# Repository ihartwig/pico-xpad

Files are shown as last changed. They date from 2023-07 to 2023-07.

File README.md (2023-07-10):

# pico-xpad
Raspberry Pi Pico Xinput focused Macropad / Gamepad

## Hardware
Folders in this repository have different hardware variations of the xpad.

### selectomatic-hw
Get you fingers ready to select as many buttons as DirectInput allows.

* 18 buttons (12 numbered keys + 4 directional keys + 2 special buttons)

### thumbs-down-hw
Pencils down folks; try out development ideas with this compact Pico + Feather Wing combo.

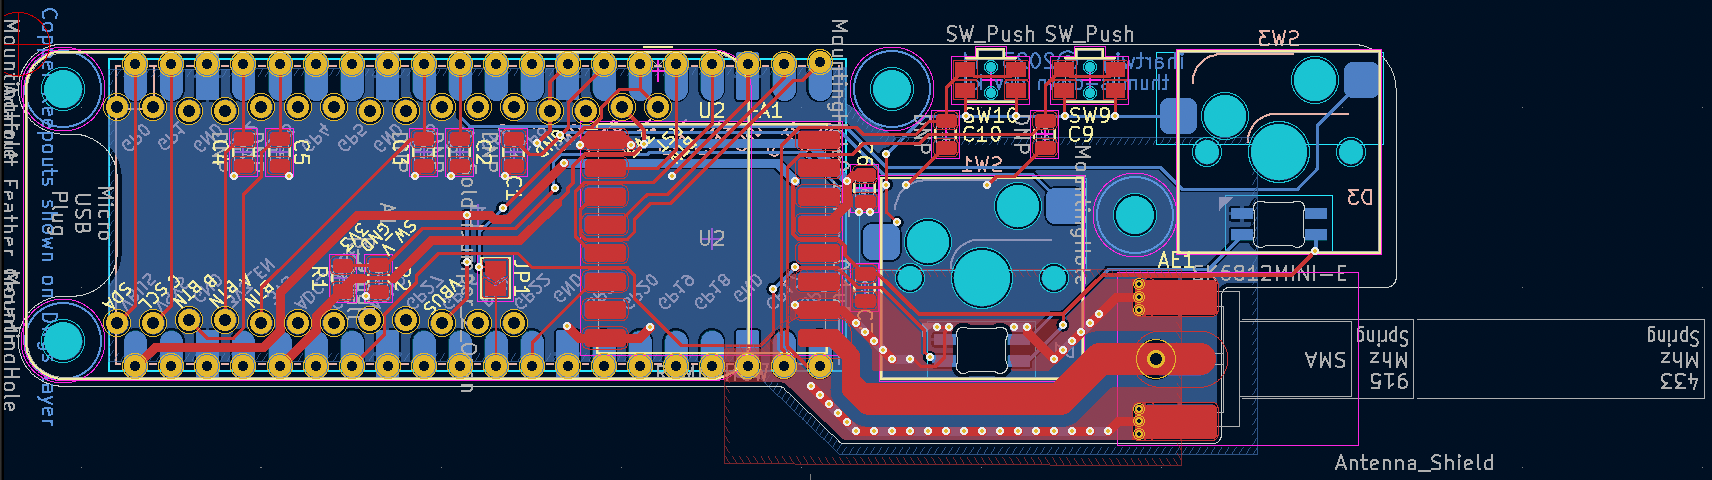
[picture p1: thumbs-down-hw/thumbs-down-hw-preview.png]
thumbs-down-hw preview


* dev kit for keys / usb / wireless with GP2040 FW or with CircuitPython 
* 4 buttons (2 keys + 2 special buttons)
* feather wing socket
** 4 more buttons w/ OLED display wing
* [RFM69HCW](https://www.adafruit.com/product/5692) module for 915/433Mhz wireless
** compact spring antenna (for [915](https://www.adafruit.com/product/4269)/[433](https://www.adafruit.com/product/4394)) or SMA connector
** footprint compatible w/ [RFM95CW](https://www.adafruit.com/product/5684) LoRA modules

## Firmware

The gamepad hardware supports running the GP2040-CE firmware out of the box.

### Compiling custom GP2040-CE firmware on MacOS

Steps to build the firmware on MacOS since this is not covered, but similar to, the steps provided in the project user guide for Linux.

```
brew update
brew install --cask gcc-arm-embedded
brew install cmake
brew install node@20
cd ~/repos
git clone https://github.com/OpenStickCommunity/GP2040-CE.git
git clone https://github.com/raspberrypi/pico-sdk.git --branch master
cd pico-sdk
git submodule update --init
cd ../
cd GP2040-CE
mkdir build
cd build
PICO_SDK_PATH=/Users/ihartwig/repos/pico-sdk cmake ..
PICO_SDK_PATH=/Users/ihartwig/repos/pico-sdk make
```

## Credits

Footprints reused from community designs:
* https://github.com/Kozova1/Macropad
* https://github.com/ebastler/kicad-keyboard-parts.pretty/
* https://datasheets.raspberrypi.com/rp2040/VGA-KiCAD.zip
* https://datasheets.raspberrypi.com/rp2040/VGA-PicoW-KiCAD.zip

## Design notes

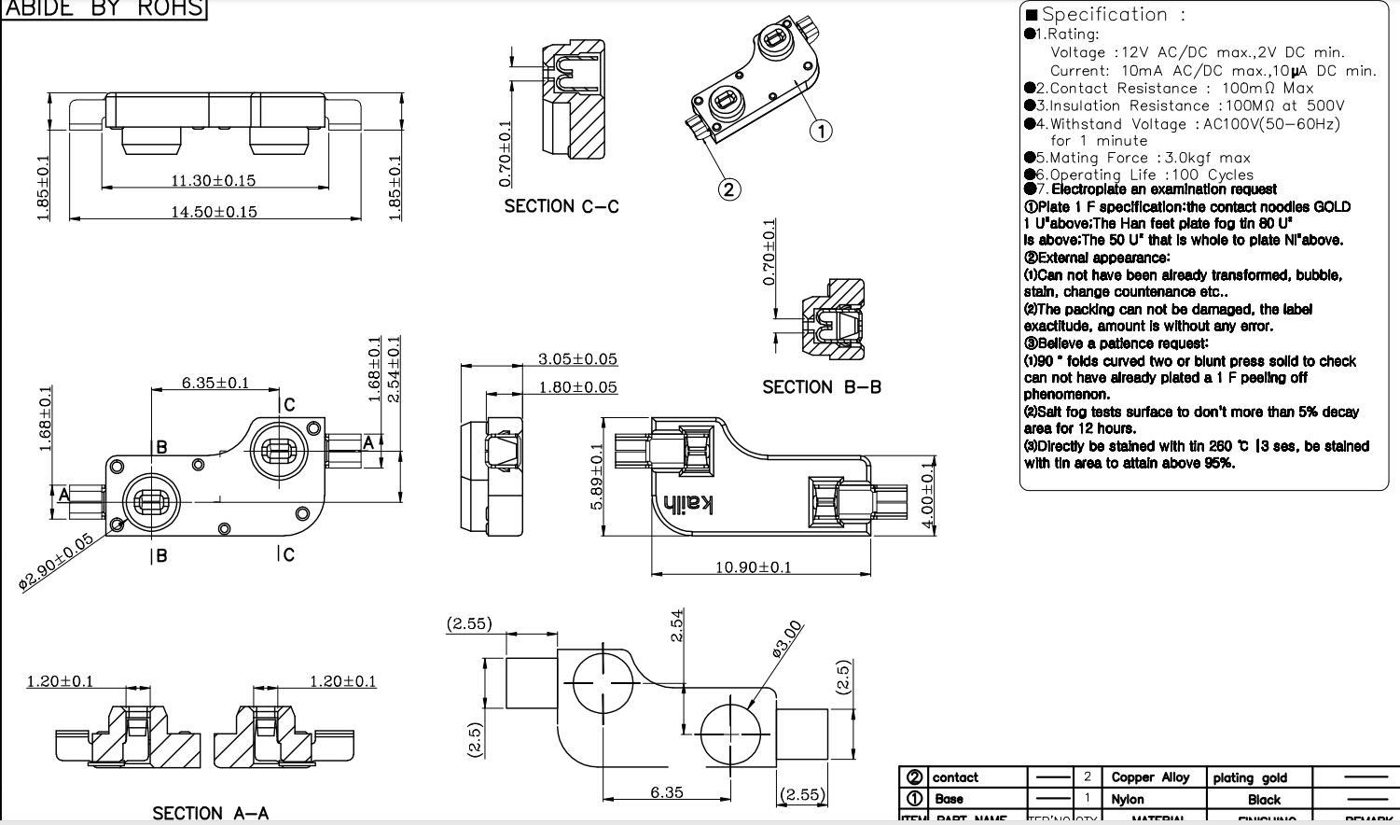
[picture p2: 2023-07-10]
docs/4958_Kailh_Key_Switch_Socket.jpeg

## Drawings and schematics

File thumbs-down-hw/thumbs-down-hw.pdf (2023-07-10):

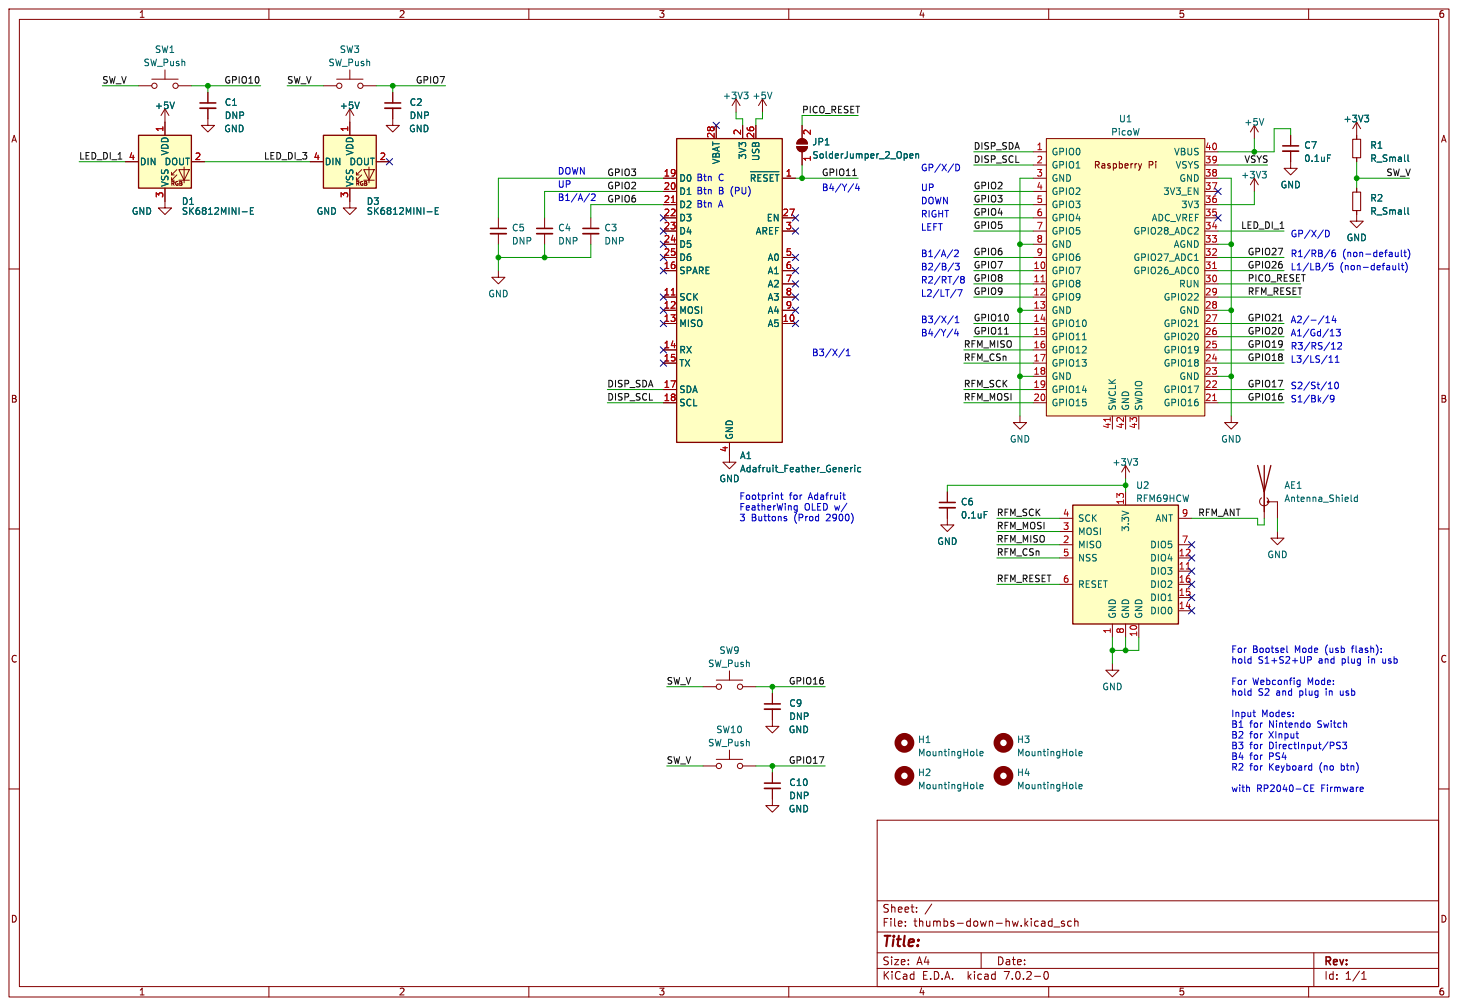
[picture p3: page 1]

2 D1 20 D2 21 D3 22 D4 23 D5 24 D6 25 USB 26 EN 27 VBAT 28 AREF 3 GND

L3/LS/11 Btn B (PU) UP

1 GND 10 DIO3 11 DIO4 12 3.3V 13 DIO0 14 DIO1 15 DIO2 16 MISO 2 MOSI 3 SCK 4 NSS 5 RESET 6 DIO5 7 GND

Id: 1/1 Title: File: thumbs-down-hw.kicad_sch Sheet: /

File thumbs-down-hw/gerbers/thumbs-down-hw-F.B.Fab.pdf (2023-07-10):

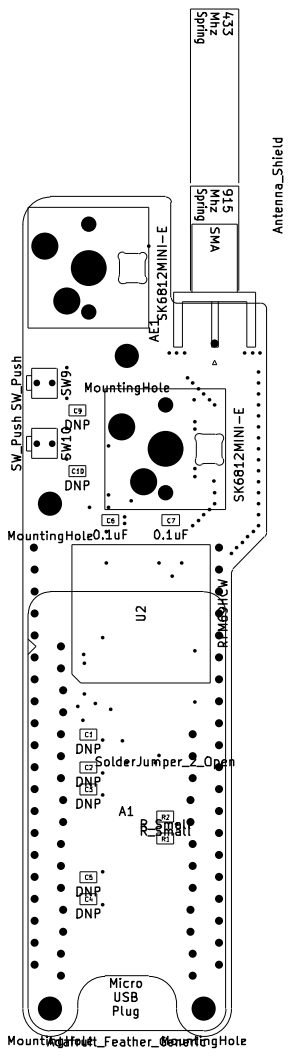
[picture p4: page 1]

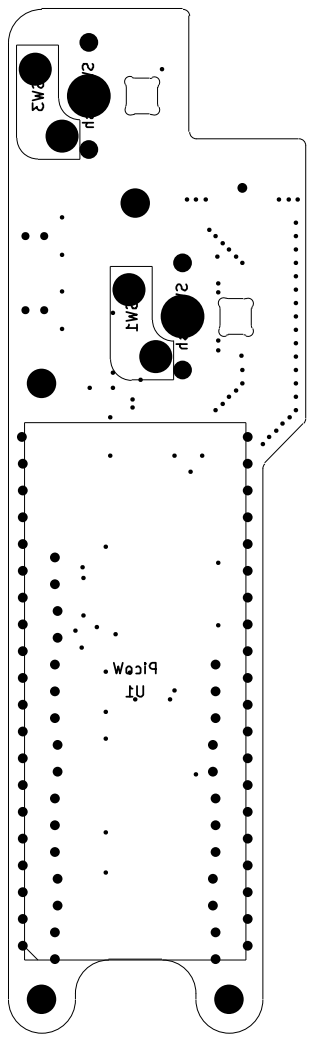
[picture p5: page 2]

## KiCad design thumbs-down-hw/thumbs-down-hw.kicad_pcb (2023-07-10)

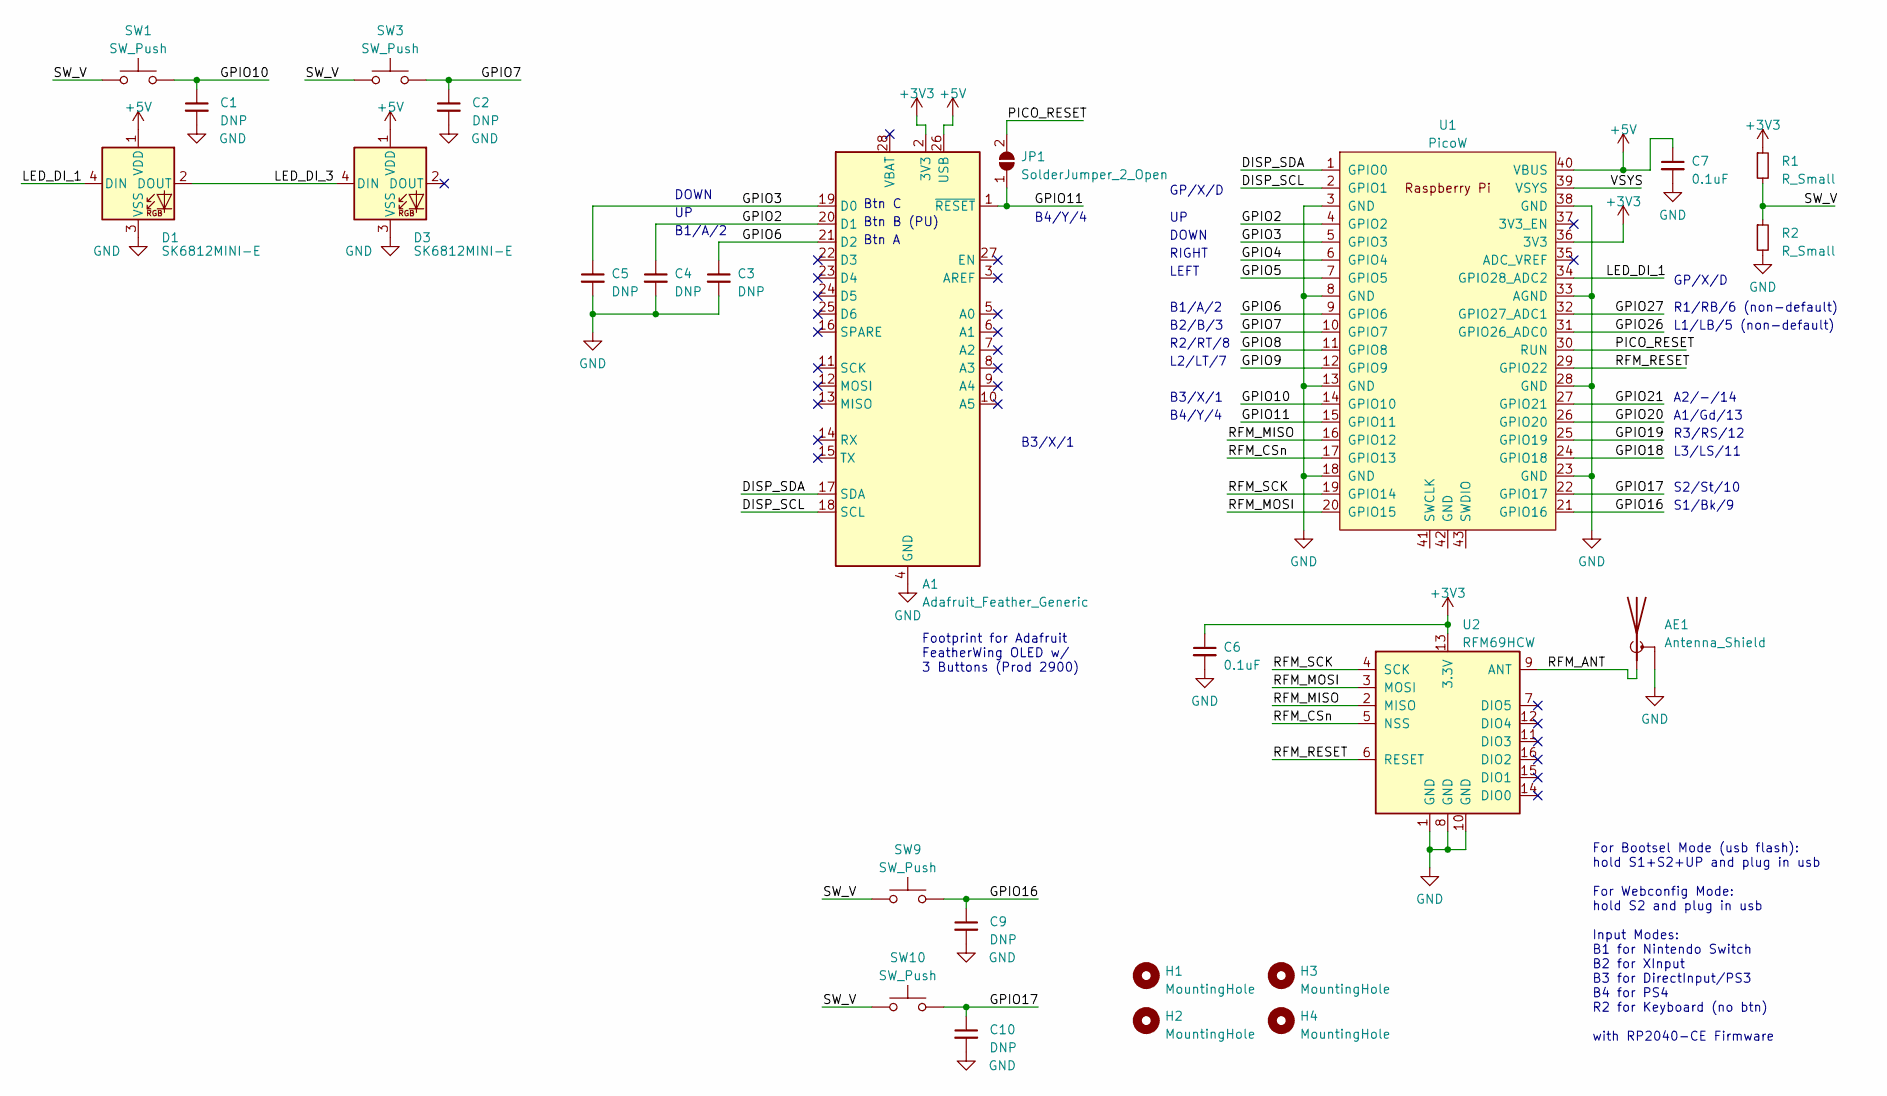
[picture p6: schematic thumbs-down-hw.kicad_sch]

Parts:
A1: Adafruit_Feather_Generic; Adafruit_Feather_Narrow
AE1: Antenna_Shield; SMA_Molex_73251-1153_EdgeMount_Horizontal_Or_Spring_Ant
C1, C2, C3, C4, C5, C9, C10: DNP; C_0805_2012Metric
C6, C7: 0.1uF; C_0805_2012Metric
D1, D3: SK6812MINI-E; LED_SK6812MINI-E_PLCC4_3.5x3.5mm_P1.75mm
H1, H2, H3, H4: MountingHole; MountingHole_2.7mm_M2.5
JP1: SolderJumper_2_Open; SolderJumper-2_P1.3mm_Open_TrianglePad1.0x1.5mm
R1: R_Small; R_0805_2012Metric
R2: R_Small; C_0805_2012Metric
SW1, SW3: SW_Push; Keyswitch_Hotswap_Kailh_1.00u
SW9, SW10: SW_Push; SW_SPST_EVQP7C
U1: PicoW; RPi_Pico_SMD_TH_Keepouts
U2: RFM69HCW; HOPERF_RFM9XW_SMD

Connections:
+3V3: A1.2 (3V3), C6.1, R1.1, U1.36 (3V3), U2.13 (3.3V)
+5V: A1.26 (USB), C7.1, D1.1 (VDD), D3.1 (VDD), U1.40 (VBUS)
/DISP_SCL: A1.18 (SCL), U1.2 (GPIO1)
/DISP_SDA: A1.17 (SDA), U1.1 (GPIO0)
/GPIO2: A1.20 (D1), C4.1, U1.4 (GPIO2)
/GPIO3: A1.19 (D0), C5.1, U1.5 (GPIO3)
/GPIO4: U1.6 (GPIO4)
/GPIO5: U1.7 (GPIO5)
/GPIO6: A1.21 (D2), C3.1, U1.9 (GPIO6)
/GPIO7: C2.1, SW3.2, U1.10 (GPIO7)
/GPIO8: U1.11 (GPIO8)
/GPIO9: U1.12 (GPIO9)
/GPIO10: C1.1, SW1.2, U1.14 (GPIO10)
/GPIO11: A1.1 (~RESET), JP1.1 (A), U1.15 (GPIO11)
/GPIO16: C9.1, SW9.2, U1.21 (GPIO16)
/GPIO17: C10.1, SW10.2, U1.22 (GPIO17)
/GPIO18: U1.24 (GPIO18)
/GPIO19: U1.25 (GPIO19)
/GPIO20: U1.26 (GPIO20)
/GPIO21: U1.27 (GPIO21)
/GPIO26: U1.31 (GPIO26_ADC0)
/GPIO27: U1.32 (GPIO27_ADC1)
/LED_DI_1: D1.4 (DIN), U1.34 (GPIO28_ADC2)
/LED_DI_3: D1.2 (DOUT), D3.4 (DIN)
/PICO_RESET: JP1.2 (B), U1.30 (RUN)
/RFM_ANT: AE1.1 (A), U2.9 (ANT)
/RFM_CSn: U1.17 (GPIO13), U2.5 (NSS)
/RFM_MISO: U1.16 (GPIO12), U2.2 (MISO)
/RFM_MOSI: U1.20 (GPIO15), U2.3 (MOSI)
/RFM_RESET: U1.29 (GPIO22), U2.6 (RESET)
/RFM_SCK: U1.19 (GPIO14), U2.4 (SCK)
/SW_V: R1.2, R2.1, SW1.1, SW3.1, SW9.1, SW10.1
/VSYS: U1.39 (VSYS)
GND: A1.4 (GND), AE1.2 (Shield), C1.2, C2.2, C3.2, C4.2, C5.2, C6.2, C7.2, C9.2, C10.2, D1.3 (VSS), D3.3 (VSS), R2.2, U1.3 (GND), U1.8 (GND), U1.13 (GND), U1.18 (GND), U1.23 (GND), U1.28 (GND), U1.33 (AGND), U1.38 (GND), U2.1 (GND), U2.8 (GND), U2.10 (GND)

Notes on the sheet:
R3/RS/12
B1/A/2
DOWN
B2/B/3
RIGHT
Btn B (PU)
GP/X/D
Btn C
A2/-/14
S2/St/10
L2/LT/7
B4/Y/4
R1/RB/6 (non-default)
B3/X/1
Footprint for Adafruit FeatherWing OLED w/ 3 Buttons (Prod 2900)
R2/RT/8
LEFT
L3/LS/11
Btn A
A1/Gd/13
For Bootsel Mode (usb flash): hold S1+S2+UP and plug in usb For Webconfig Mode: hold S2 and plug in usb Input Modes: B1 for Nintendo Switch B2 for XInput B3 for DirectInput/PS3 B4 for PS4 R2 for Keyboard (no btn) with RP2040-CE Firmware
S1/Bk/9
L1/LB/5 (non-default)

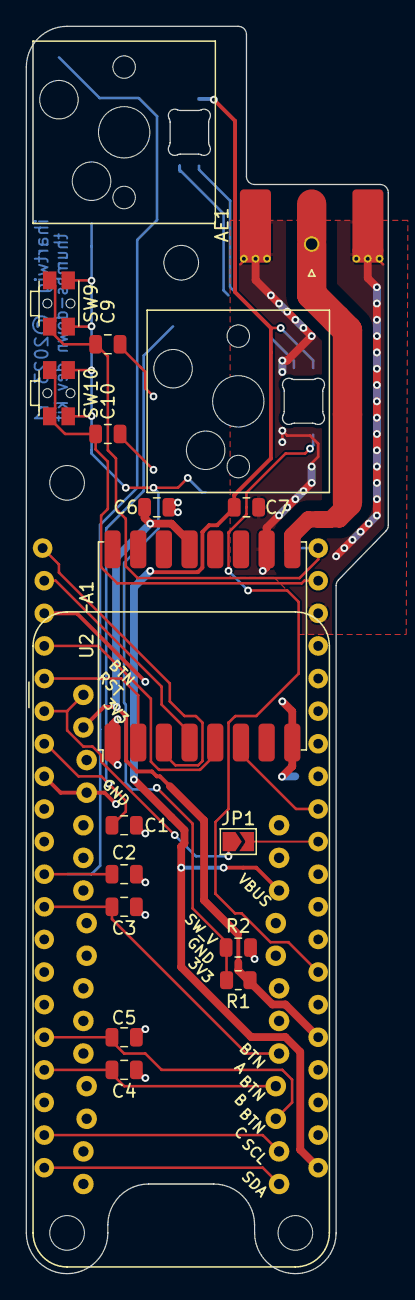
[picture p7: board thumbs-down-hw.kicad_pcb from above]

Board: 2 copper layers, 28.2 x 97.2 mm, 26 parts (1 on the bottom side), 23 nets.

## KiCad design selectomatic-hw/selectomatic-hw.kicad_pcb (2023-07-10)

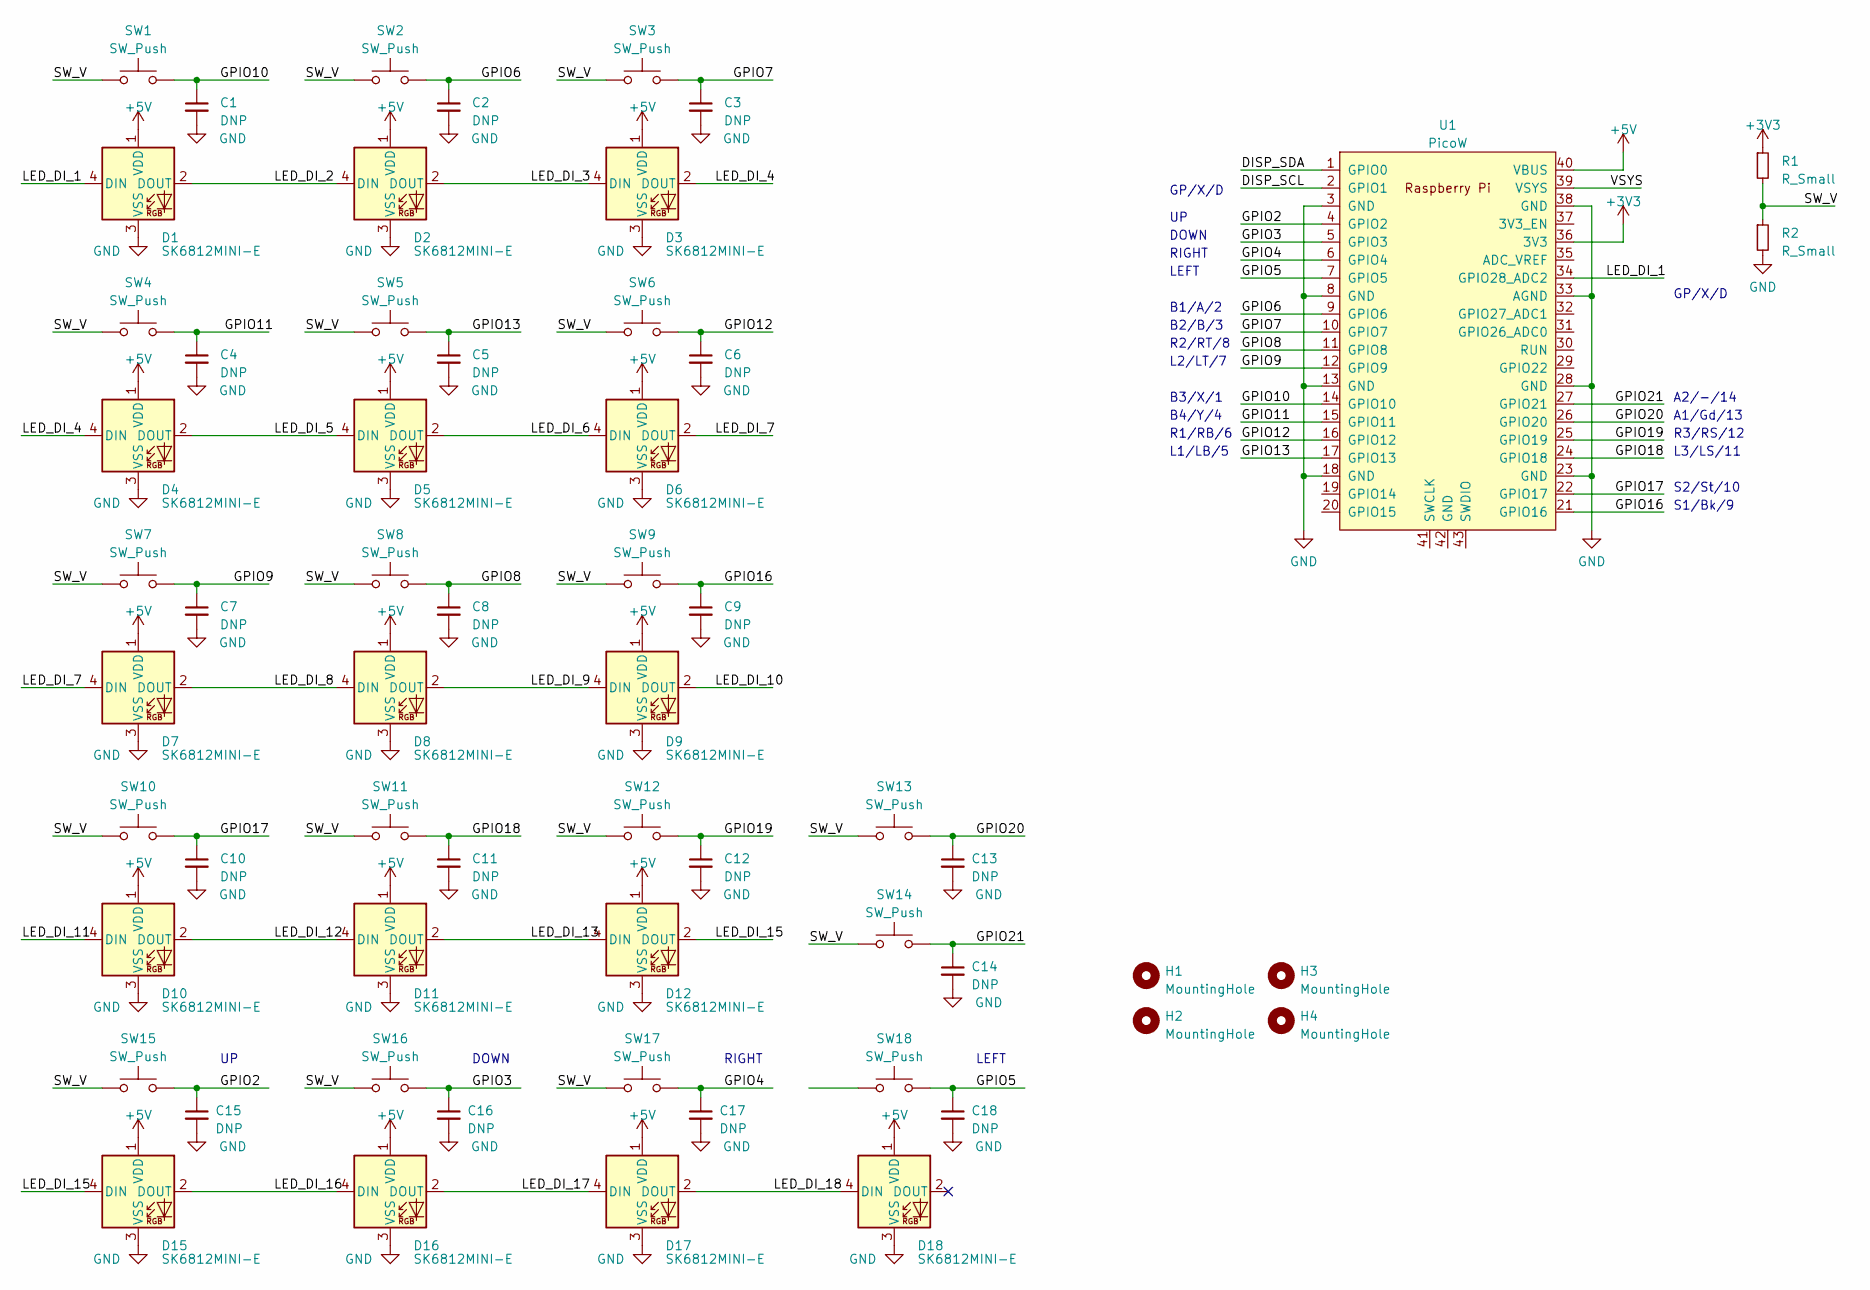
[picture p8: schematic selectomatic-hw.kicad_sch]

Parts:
C1, C2, C3, C4, C5, C6, C7, C8, C9, C10, C11, C12, C13, C14, C15, C16, C17, C18: DNP; C_0805_2012Metric
D1, D2, D3, D4, D5, D6, D7, D8, D9, D10, D11, D12, D15, D16, D17, D18: SK6812MINI-E; LED_SK6812MINI-E_PLCC4_3.5x3.5mm_P1.75mm
H1, H2, H3, H4: MountingHole
R1: R_Small; R_0805_2012Metric
R2: R_Small; C_0805_2012Metric
SW1, SW2, SW3, SW4, SW5, SW6, SW7, SW8, SW9, SW10, SW11, SW12, SW15, SW16, SW17, SW18: SW_Push; Keyswitch_Hotswap_Kailh_1.00u
SW13, SW14: SW_Push; SW_SPST_TL3342
U1: PicoW; RPi_PicoW_SMD_TH

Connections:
+3V3: R1.1, U1.36 (3V3)
+5V: D1.1 (VDD), D2.1 (VDD), D3.1 (VDD), D4.1 (VDD), D5.1 (VDD), D6.1 (VDD), D7.1 (VDD), D8.1 (VDD), D9.1 (VDD), D10.1 (VDD), D11.1 (VDD), D12.1 (VDD), D15.1 (VDD), D16.1 (VDD), D17.1 (VDD), D18.1 (VDD), U1.40 (VBUS)
/DISP_SCL: U1.2 (GPIO1)
/DISP_SDA: U1.1 (GPIO0)
/GPIO2: C15.1, SW15.2, U1.4 (GPIO2)
/GPIO3: C16.1, SW16.2, U1.5 (GPIO3)
/GPIO4: C17.1, SW17.2, U1.6 (GPIO4)
/GPIO5: C18.1, SW18.2, U1.7 (GPIO5)
/GPIO6: C2.1, SW2.2, U1.9 (GPIO6)
/GPIO7: C3.1, SW3.2, U1.10 (GPIO7)
/GPIO8: C8.1, SW8.2, U1.11 (GPIO8)
/GPIO9: C7.1, SW7.2, U1.12 (GPIO9)
/GPIO10: C1.1, SW1.2, U1.14 (GPIO10)
/GPIO11: C4.1, SW4.2, U1.15 (GPIO11)
/GPIO12: C6.1, SW6.2, U1.16 (GPIO12)
/GPIO13: C5.1, SW5.2, U1.17 (GPIO13)
/GPIO16: C9.1, SW9.2, U1.21 (GPIO16)
/GPIO17: C10.1, SW10.2, U1.22 (GPIO17)
/GPIO18: C11.1, SW11.2, U1.24 (GPIO18)
/GPIO19: C12.1, SW12.2, U1.25 (GPIO19)
/GPIO20: C13.1, SW13.2, U1.26 (GPIO20)
/GPIO21: C14.1, SW14.2, U1.27 (GPIO21)
/LED_DI_1: D1.4 (DIN), U1.34 (GPIO28_ADC2)
/LED_DI_2: D1.2 (DOUT), D2.4 (DIN)
/LED_DI_3: D2.2 (DOUT), D3.4 (DIN)
/LED_DI_4: D3.2 (DOUT), D4.4 (DIN)
/LED_DI_5: D4.2 (DOUT), D5.4 (DIN)
/LED_DI_6: D5.2 (DOUT), D6.4 (DIN)
/LED_DI_7: D6.2 (DOUT), D7.4 (DIN)
/LED_DI_8: D7.2 (DOUT), D8.4 (DIN)
/LED_DI_9: D8.2 (DOUT), D9.4 (DIN)
/LED_DI_10: D9.2 (DOUT)
/LED_DI_11: D10.4 (DIN)
/LED_DI_12: D10.2 (DOUT), D11.4 (DIN)
/LED_DI_13: D11.2 (DOUT), D12.4 (DIN)
/LED_DI_15: D12.2 (DOUT), D15.4 (DIN)
/LED_DI_16: D15.2 (DOUT), D16.4 (DIN)
/LED_DI_17: D16.2 (DOUT), D17.4 (DIN)
/LED_DI_18: D17.2 (DOUT), D18.4 (DIN)
/SW_V: R1.2, R2.1, SW1.1, SW2.1, SW3.1, SW4.1, SW5.1, SW6.1, SW7.1, SW8.1, SW9.1, SW10.1, SW11.1, SW12.1, SW13.1, SW14.1, SW15.1, SW16.1, SW17.1
/VSYS: U1.39 (VSYS)
GND: C1.2, C2.2, C3.2, C4.2, C5.2, C6.2, C7.2, C8.2, C9.2, C10.2, C11.2, C12.2, C13.2, C14.2, C15.2, C16.2, C17.2, C18.2, D1.3 (VSS), D2.3 (VSS), D3.3 (VSS), D4.3 (VSS), D5.3 (VSS), D6.3 (VSS), D7.3 (VSS), D8.3 (VSS), D9.3 (VSS), D10.3 (VSS), D11.3 (VSS), D12.3 (VSS), D15.3 (VSS), D16.3 (VSS), D17.3 (VSS), D18.3 (VSS), R2.2, U1.3 (GND), U1.8 (GND), U1.13 (GND), U1.18 (GND), U1.23 (GND), U1.28 (GND), U1.33 (AGND), U1.38 (GND)

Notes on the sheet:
R3/RS/12
DOWN
B2/B/3
LEFT
RIGHT
GP/X/D
A2/-/14
S2/St/10
L2/LT/7
B4/Y/4
R1/RB/6
B3/X/1
R2/RT/8
L3/LS/11
B1/A/2
A1/Gd/13
S1/Bk/9
L1/LB/5

Board: 2 copper layers, 55 parts (1 on the bottom side), 37 nets, no tracks yet.

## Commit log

2023-07-10 setup libs and add selectomatic-hw and thumb-down-hw drafts
    [selectomatic-hw.kicad_pcb, selectomatic-hw.kicad_sch, thumb-down-hw.kicad_pcb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]
2023-07-10 rename thumbs-down-hw
    [thumbs-down-hw.kicad_pcb, thumbs-down-hw.kicad_sch]
2023-07-10 add thumbs-down-hw r1 gerbers
    [thumbs-down-hw-B_Cu.gbr, thumbs-down-hw-B_Mask.gbr, thumbs-down-hw-B_Paste.gbr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]

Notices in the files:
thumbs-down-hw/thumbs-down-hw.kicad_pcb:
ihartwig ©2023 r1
